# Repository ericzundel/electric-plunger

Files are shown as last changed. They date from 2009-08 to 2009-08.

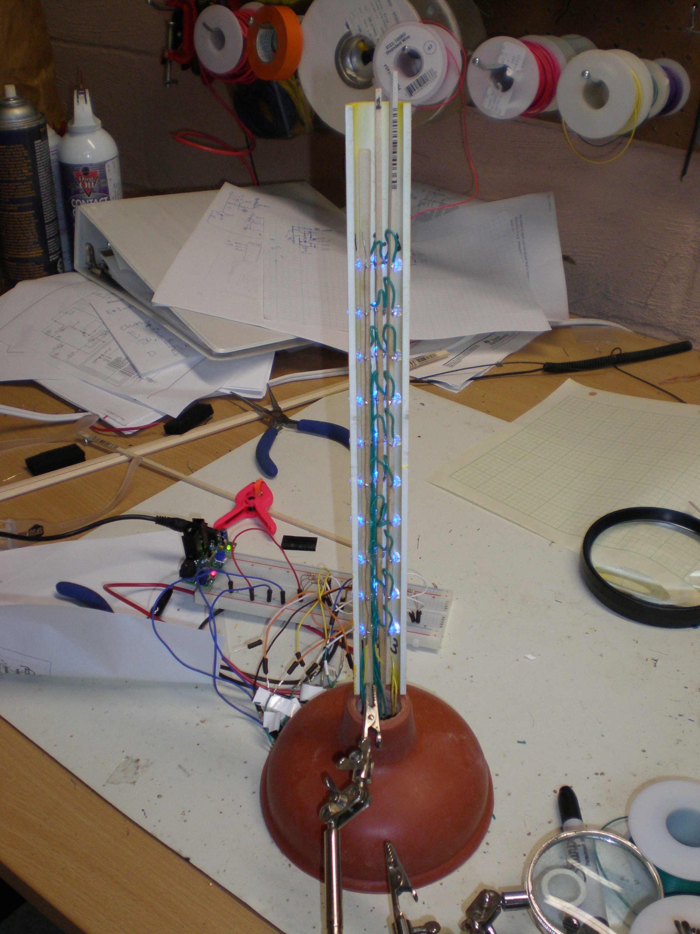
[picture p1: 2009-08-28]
ElectricPlunger/photos/plunger-inside.jpg

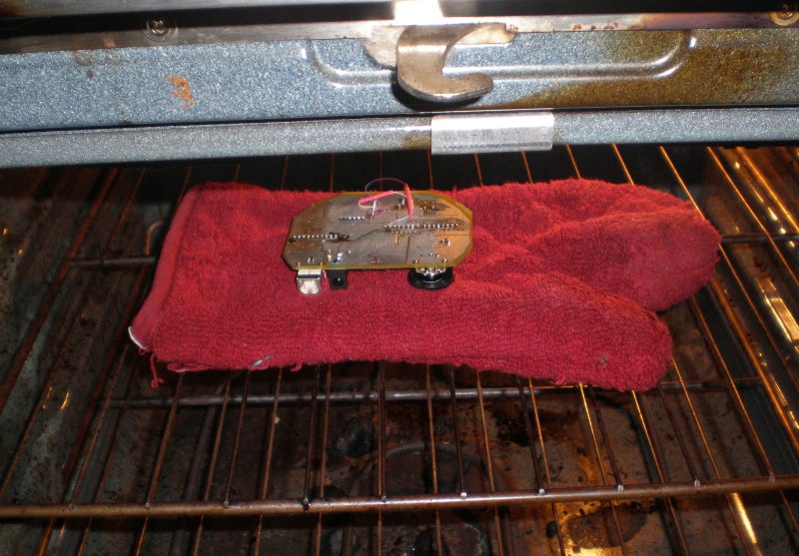
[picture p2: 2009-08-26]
ElectricPlunger/photos/whats-cookin.jpg

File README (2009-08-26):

This is the repo for a project that builds an Electric Plunger.  

ATTRIBUTION:

The plunger circuit and software was written by Eric Z. Ayers.

The plunger circuit is originally based on:

  The Arduino Project: 
    http://arduino.cc
  The Adafruit wave shield by Limor Fried: 
    http://adafruit.com

The software uses:

  The Arduino development environment (version 17) downloadable from:
    http://arduino.cc
  The WaveHC library by Bill Greiman (fat16): 
    http://code.google.com/p/wavehc
  Which in turn was based on Limor Fried's AF_Wave library:
    http;//ladyada.net/

In addition, I used AVRStudio and an AVRISPmkII to flash the bootloader
to the ATMega386P.

LICENSE:

The code, circuits and other materials in this project may be re-used 
or distributed under the terms of the Creative Commons Attribution 3.0 
License.

See LICENSE for more details

SOURCE REPO:

There is a public source code repo that can be accessed with 'git' using the 
remote specification:
  git@github.com:ericzundel/electric-plunger.git

CONTENTS:

ElectricPlunger/  Contains the project files for the ElectricPlunger project
SoundDemo/        Sample code that just plays audio files (no led drivers)
wavelib/          Other goodies from Bill Greimen's WaveHC library
libraries/        Contains the libraries used by the project.

-Eric.
--
Eric Z. Ayers
Aug 26 2009

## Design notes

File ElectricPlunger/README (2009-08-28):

These sketches are a part of the Electric Plunger project.

The plunger has LEDs on its handle that light up and make a show.
There are electronics and a speaker in the base.  The circuit contains
a DAC to play music and a sdcard reader for storing data.

circuit - schematics and board files used to design the electronics.

led_matrix_development - a sketch that drives the LED matrix as a state
    machine.  This was in preparation for writing the LedMatrix library.

led_matrix_demo - a sketch that demonstrates using the LedMatrix library.

led_files - Some sample .led files that are read by the plunger_driver project

photos - Photos of the development of the projecct.

plunger_driver - The code that was actually loaded into the electric plunger
    to read .wav and .led files and display them.

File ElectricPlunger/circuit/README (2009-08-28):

These files pertain the to ElectricPlunger circuit.

plunger-smt.brd - current Eagle 5.6.0 board file (http://cadsoftusa.com)
plunger-smt.sch - current Eagle 5.6.0 schematic file
v0.2/ - a schematic I posted for comments on forums.ladyada.net
v0.2.1/ - the first version of the board I sent off to 4pcb.com for prototyping

The circuit is a mashup of:
  - Arduino Duemilanove board (http://arduino.cc)
  - Adafruit Wave shield  (http://ladyada.net)
  - A custom LED matrix driver

All parts were sourced from Mouser, and the board manufactured by 4pcb.com

DESIGN NOTES:

Power:

- The PTC is a life saver.  Without it I would have burned up the 
  prototypes about a dozen tims.
- The KFBDT regulator data sheets require just 2.2uf caps, but I went 
  conservative and put in bigger 100uf caps.
- Routing a 5V line under the 3.3V output of the 3.3V regulator was a bad 
  idea.  I couldn't see under there and I thoguht I might have shorted the 
  two traces.

Audio:

- Limor Fried suggested that upgrading TL07 opamp to a better audio 
  amp (she suggested an LM386) would be a good idea.
- I fretted over making sure the audio circuit was not noisy.  Getting
  the grounds correct on a mixed analog/digital circuit are norotoriously
  difficult.  I followed the advice I found here:
    http://www.hottconsultants.com/techtips/split-gnd-plane.html
  and here:
    http://www.atmel.com/dyn/resources/prod_documents/doc7633.pdf
  The board turned out well, the audio quality was very good (although 
   not very loud.)
- To eliminate noise, I added decoupling caps around most chips, but not 
  all.  I should make sure each chip has one if I do another board.

USB:
 
- The USB on the v0.2.1 schematic is completely messed up.  
    o TX and RX need to be switched 
    o TEST needs to go to ground
    o DTR needs to be connected to the cap before the RESET
      line (to enable the Arduini auto-reset function)
- When using the USB-TTL cable, the auto-reset doesn't work - you have
  to hit the reset button when the Arduino env. is ready to upload to
  the chip.
- If we intend to have both the on-board USB and the USB-TTL work, there
  has to be some kind of way to isolate so that both TX lines from USB 
  don't interfere with each other (a switch?)

LED Matrix:

- The current limiting resistors mean that each line attached to the 
  ULN2803 should only drive one LED at a time.  I should have put them
  after the PNP transistors because then we could drive 10 LEDs at a time
  instead of only 6, meaning we wouldn't have as much flicker and the 
  matrix might be less timing sensitive.
- After the board was made, someone suggested we add a vibrating motor.  That
  could be driven by one of the spare ULN2803 lines.

MPU:

- I swapped out a 20MHz crystal for the original 16MHz one to try to get rid
  of flicker in the LED matrix (it didn't work.).  This means that I had to
  re-compile a custom bootloader.
- Bringing out all the pins to headers was a good idea. I used this a lot
  for debugging the prototype board.
- I did not wire up the snd enable or brightness controls in the prototype.
  An external button to swich to the next song (or reset the circuit) would
  have been good.
- I considered going to 3.3V on the MPU and then just leaving USB 5V or 
  unregulated power going to the LED matrix.  Then, I could have talked 
  to the SDCard directly with no buffer in between.  However, I would have 
  to add more components for controlling the Led Matrix PNP transistors 
  from 3.3V logic.

Other:

- I didn't really work out how to mount the speaker before assembling 
  everything.   Stuffing it inside the plunger bottom had lots of issues.
   o I tried hot gluing the speaker to the rubber, but it didn't stick.
   o The speaker is heavy and has potential to damage the circuit board
      if it isn't secured
   o the speaker leads are prone to get damaged and will cause crappy sound
   o A speaker mounted inside a rubber plunger bottom is not the ideal
      acoustical environment.

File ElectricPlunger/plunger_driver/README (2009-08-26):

This is the driver shipped with the original Electric plunger on 26 Aug.

It plays .wav files and flashes the LED matrix.
The .wav and .led files must reside in the root directory

The WaveHC file is from http://code.google.com/p/WaveHC
The LedMatrix library is something I wrote.

The WaveHC API accesses the SdReader and FatReader APIs from inside an
interrupt making the LedMatrix flash a lot.  I modified the WaveHC
file to run the LedMatrix state machine more frequently by passing in
a function to run while those libraries are stooging around waiting
for the sdcard to respond.

Notes:

*** Don't leave the plunger turned on with the card un-installed.  The EEPROM 
has a limited number of writes (100,000) over its lifetime.  I fear that 
this would cause the writes to cycle quickly (but this is unconfirmed)

* To further extend the life of the EEPROM, use long LED files and audio clips 
instead of lots of short ones, *or* change th code to write to the EEPROM less 
frequently, if at all.

- The crystal on the original plunger is 20 MHz and the Arduino 
development environment expects 16 MHz board.  I cloned the 16MHz Duemilanove
board description in boards.txt and changed the frequency to 20000000.

-Eric
Wed Aug 26 10:34:33 EDT 2009

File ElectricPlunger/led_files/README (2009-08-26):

These files are the data to drive the LED display.  Format is ASCII.

Each line describes a pattern to display in the LED matrix.  The line length
is 65 characters (including a terminating newline)  The files can be arbitrarily
long.  As a practical matter, the SD cars has a lot of capacity, and since 
there is a stutter in the music when opening a new file, it would be
better to make fewer long files than lots of short files.

The first 4 characters are 4 ascii digits [0-9] that encode the time to display
this sequence in milliseconds.  

The next 60 characters descrive the values for each of the rows.
0 == LED off
1-4 == LED on

(Originally, the matrix could display different intensitites, but when playing 
music and driving the LED, there was unacceptable flickering)

Examples:

Display the first row for 1 second:
1000111111000000000000000000000000000000000000000000000000000000

Display the second row for 1 second:
1000000000111111000000000000000000000000000000000000000000000000

Display the first column for 1 second
1000100000100000100000100000100000100000100000100000100000100000

Display all leds on for a quarter second, then turn them off 
for a quarter second:
0250111111111111111111111111111111111111111111111111111111111111
0250000000000000000000000000000000000000000000000000000000000000

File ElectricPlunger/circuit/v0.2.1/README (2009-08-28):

These are the files that were sent to the PCB fab to make the 
prototype circuit board.

 plunger-smt.brd - EAGLE Circuit board layout (http://cadsoft.de)
 plunger-smt.sch - EAGLE Schematic
 parts.txt - exported parts list from Eagle
 plunger-smt.G?? - gerber files sent to the fab (http://barebonespcb.com)
 plunger-smt.TXT - drill file sent to the fab (http://barebonespcb.com)

Here are the problems I found after v0.2.1:

- The Power adapter had leads that required bigger holes than provided by 
  the part.
- Add a power LED
- Add a power switch
- RS232L and USB-TTL cable: RX and TX need to be swapped.
- RS232RL chip: TEST needs to go to GROUND
- RS232RL chip: needs to have DTR wired to reset, not RTS#
- USB-TTL cable: I added a 1K resistor in series for both RX and TX since 
  it is going between 5V and 3.3V logic
- The USB to TTL cable will not work if the 232RL chip is installed because 
  there will be multiple drivers of the serial line.  Since I couldn't get the 
  on-board USB to work, I cut those traces and used the FTDI USB to TTL cable 
  instead.
- The board would have been better designed with the current limiting resistor
  after the PNP transistors instead of in front of the darlington array.   
  Then the LED matrix could cycle through 6 columns instead of 10 rows 
  (less flicker.)
- Add a connection for an external switch to be mounted on the plunger to 
  advance to the next track.  Could use the reset line on SV8.

Eric Ayers
ericzundel@gmail.com
Wed Aug 26 09:44:39 EDT 2009

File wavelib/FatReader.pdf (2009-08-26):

# Arduino FatReader Library

Copyright (C) 2009 by William Greiman

## Introduction

The Arduino FatReader Library is a minimal implementation of a reader for FAT16 and FAT32 file systems on SD flash memory cards. Standard SD and high capacity SDHC cards are supported.
The FatReader class only supports short 8.3 names.
Short 8.3 names are limited to 8 characters followed by an optional period (.) and extension of up to 3 characters.
The characters may be any combination of uppercase letters and digits. The following special characters are also allowed:
$ % ' - _ @ ~ ` ! ( ) { } ^ # &

## Hardware Configuration

FatReader was developed using an Adafruit Industries Wave Shield. See the Schematic for details.

## Warning

FatReader has been tested with several SD Cards but is bound to contain many bugs. In most companies this would be called pre-alpha software. I hope people will try it and send me comments.

## Bugs and Comments

If you wish to report bugs or have comments, send email to fat16lib@sbcglobal.net.

## References

Adafruit Industries:

http://www.adafruit.com/

http://www.ladyada.net/make/waveshield/

Schematic - http://www.ladyada.net/make/waveshield/download.html The Arduino site:

http://www.arduino.cc/
For more information about FAT file systems see:

http://www.microsoft.com/whdc/system/platform/firmware/fatgen.msp x
For information about using SD cards as SPI devices see:

http://www.sdcard.org/developers/tech/sdcard/pls/Simplified_Physical_Layer_Spec.pdf
The ATmega168 datasheet:

http://www.atmel.com/dyn/resources/prod_documents/doc8025.pdf

# Class Index

## Class List

Here are the classes, structs, unions and interfaces with brief descriptions:

# File Index

## File List

Here is a list of all files with brief descriptions:

Main/WaveHCmainpage.h | Error! Bookmark not defined.

# Class Documentation

## FatReader Class Reference

FatReader implements a minimal FAT16/FAT32 file reader class.

#include <FatReader.h>

Collaboration diagram for FatReader:

### Public Member Functions

- void close (void)
- FatReader (void)
- uint32_t fileSize (void)
- uint32_t firstCluster (void)
- uint8_t isDir (void)
- uint8_t isFile (void)
- uint8_t isOpen (void)

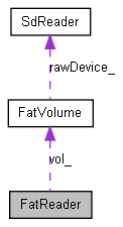
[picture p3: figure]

- uint8_t open (FatReader &dir, char *name)
- uint8_t open (FatVolume &vol, dir_t &dir)
- uint8_t openRoot (FatVolume &vol)
- int16_t read (uint8_t *dst, uint16_t count)
- uint32_t readCluster (void)
- int8_t readDir (dir_t &dir)
- uint32_t readPosition (void)
- void rewind (void)
- uint8_t seekCur (uint32_t pos)
- uint8_t seekSet (uint32_t pos)
- uint8_t type (void)
- FatVolume * volume (void)

### Detailed Description

FatReader implements a minimal FAT16/FAT32 file reader class.

### Constructor & Destructor Documentation

FatReader::FatReader (void) [inline]
Create an instance of FatReader.

### Member Function Documentation

void FatReader::close (void) [inline] Close this instance of FatReader.

uint32_t FatReader::fileSize (void) [inline]

Returns:
The total number of bytes in a file or directory.

uint32_t FatReader::firstCluster (void) [inline]

Returns:
The first cluster number for a file or directory.

uint8_t FatReader::isDir (void) [inline]

Returns:
True if this is a FatReader for a directory else false

uint8_t FatReader::isFile (void) [inline]

Returns:
True if this is a FatReader for a file else false

uint8_t FatReader::isOpen (void) [inline]

Returns:
True if this is a FatReader for an open file/directory else false

uint8_t FatReader::open (FatReader & dir, char * name) Open a file or subdirectory by name.

Note:
The file or subdirectory, name , must be in the specified directory, dir , and must have a DOS 8.3 name.
Parameters:
dir An open FatReader instance for the directory.
name A valid 8.3 DOS name for a file or subdirectory in the directory dir .
Returns:
The value one, true, is returned for success and the value zero, false, is returned for failure. Reasons for failure include the FAT volume has not been initialized, dir is not a directory, name is invalid, the file or subdirectory does not exist, or an I/O error occurred.

uint8_t FatReader::open (FatVolume & vol, dir_t & dir)
Open a file or subdirectory by directory structure.

Parameters:
vol The FAT volume that contains the file or subdirectory.
dir The directory structure describing the file or subdirectory.
Returns:
The value one, true, is returned for success and the value zero, false, is returned for failure. Reasons for failure include the FAT volume, vol , has not been initialized, vol is a FAT12 volume or dir is not a valid directory entry.

uint8_t FatReader::openRoot (FatVolume & vol)
Open a volume's root directory.

Parameters:
vol The FAT volume containing the root directory to be opened.
Returns:
The value one, true, is returned for success and the value zero, false, is returned for failure. Reasons for failure include the FAT volume has not been initialized or it a FAT12 volume.

int16_t FatReader::read (uint8_t * dst, uint16_t count)
Read data from a file at starting at the current read position.

Parameters:
dst Pointer to the location that will receive the data.
count Maximum number of bytes to read.
Returns:
For success read() returns the number of bytes read. A value less than count , including zero, will be returned if end of file is reached. If an error occurs, read() returns -1. Possible errors include read() called before a file has been opened, corrupt file system or an I/O error occurred.

uint32_t FatReader::readCluster (void) [inline]

Returns:
The current cluster number for a file or directory.

int8_t FatReader::readDir (dir_t & dir)
Read the next directory entry from a directory file.

Parameters:
dir The dir_t struct that will receive the data.
Returns:
For success readDir() returns the number of bytes read. A value of zero will be returned if end of file is reached. If an error occurs, readDir() returns -1. Possible errors include readDir() called before a directory has been opened, this is not a directory file or an I/O error occurred.

uint32_t FatReader::readPosition (void) [inline]

Returns:
The read position for a file or directory.

void FatReader::rewind (void)
Set read position to start of file

uint8_t FatReader::seekCur (uint32_t offset)
Set the read position for a file or directory to the current position plus offset .

Parameters:
offset The amount to advance the read position.
Returns:
The value one, true, is returned for success and the value zero, false, is returned for failure.

uint8_t FatReader::seekSet (uint32_t pos) [inline]
Set the read position for a file or directory to pos .

Parameters:
pos The new read position in bytes from the beginning of the file.
Returns:
The value one, true, is returned for success and the value zero, false, is returned for failure.

uint8_t FatReader::type (void) [inline]
Type of this FatReader. You should use isFile() or isDir() instead of type() if possible.

Returns:
The file or directory type.

FatVolume* FatReader::volume (void) [inline] Parent volume

The documentation for this class was generated from the following files:

- C:/Arduino/arduino15/hardware/libraries/WaveHC/FatReader.h
- C:/Arduino/arduino15/hardware/libraries/WaveHC/FatReader.cpp

## FatVolume Class Reference

FatVolume provides access to FAT volumes.

#include <FatReader.h>

Collaboration diagram for FatVolume:

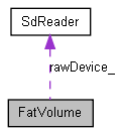
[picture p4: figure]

### Public Member Functions

- uint8_t blocksPerCluster (void)
- uint32_t blocksPerFat (void)
- uint32_t clusterCount (void)
- uint32_t dataStartBlock (void)
- uint8_t fatCount (void)
- uint32_t fatStartBlock (void)
- uint8_t fatType (void)
- FatVolume (void)
- uint8_t init (SdReader &dev, uint8_t part)
- uint8_t init (SdReader &dev)
- SdReader * rawDevice (void)
- uint32_t rootDirEntryCount (void)
- uint32_t rootDirStart (void)
- uint32_t totalBlocks (void)

### Friends

- class FatReader

### Detailed Description

FatVolume provides access to FAT volumes.

### Constructor & Destructor Documentation

FatVolume::FatVolume (void) [inline] Create an instance of FatVolume

### Member Function Documentation

uint8_t FatVolume::blocksPerCluster (void) [inline]

Returns:
The volume's cluster size in blocks.

uint32_t FatVolume::blocksPerFat (void) [inline]

Returns:
The number of blocks in one FAT.

uint32_t FatVolume::clusterCount (void) [inline]

Returns:
The total number of clusters in the volume.

uint32_t FatVolume::dataStartBlock (void) [inline]

Returns:
The logical block number for the start of file data.

uint8_t FatVolume::fatCount (void) [inline]

Returns:
The number of FAT structures on the volume.

uint32_t FatVolume::fatStartBlock (void) [inline]

Returns:
The logical block number for the start of the first FAT.

uint8_t FatVolume::fatType (void) [inline]

Returns:
The FAT type of the volume. Values are 12, 16 or 32.

uint8_t FatVolume::init (SdReader & dev, uint8_t part) Initialize a FAT volume.

Parameters:
dev The SD card where the volume is located.
part The partition to be used. Legal values for part are 1-4 to use the corresponding partition on a device formatted with a MBR, Master Boot Record, or zero if the device is formatted as a super floppy with the FAT boot sector in block zero.
Returns:
The value one, true, is returned for success and the value zero, false, is returned for failure. Reasons for failure include not finding a valid partition, not finding a valid FAT file system in the specified partition or an I/O error.

uint8_t FatVolume::init (SdReader & dev) [inline]
Initialize a FAT volume. Try partition one first then try super floppy format.

Parameters:
dev The SdReader where the volume is located.
Returns:
The value one, true, is returned for success and the value zero, false, is returned for failure. Reasons for failure include not finding a valid partition, not finding a valid FAT file system or an I/O error.

SdReader* FatVolume::rawDevice (void) [inline]
Raw device for this volume uint32_t FatVolume::rootDirEntryCount (void) [inline]

Returns:
The number of entries in the root directory for FAT16 volumes.

uint32_t FatVolume::rootDirStart (void) [inline]

Returns:
The logical block number for the start of the root directory on FAT16 volumes or the first cluster number on FAT32 volumes.

uint32_t FatVolume::totalBlocks (void) [inline]

Returns:
The total number of blocks in the volume.

### Friends And Related Function Documentation

friend class FatReader [friend]
Allow FatReader access to FatVolume private data.

The documentation for this class was generated from the following files:

- C:/Arduino/arduino15/hardware/libraries/WaveHC/FatReader.h
- C:/Arduino/arduino15/hardware/libraries/WaveHC/FatReader.cpp

## SdReader Class Reference

Hardware access class for SD flash cards.

#include <SdReader.h>

### Public Member Functions

- uint32_t cardSize (void)
- uint8_t errorCode (void)
- uint8_t errorData (void)
- uint8_t init (uint8_t slow=0)
- void partialBlockRead (uint8_t value)
- uint8_t readBlock (uint32_t block, uint8_t *dst)
- uint8_t readCID (cid_t &cid)
- uint8_t readCSD (csd_t &csd)
- uint8_t readData (uint32_t block, uint16_t offset, uint8_t *dst, uint16_t count)
- void readEnd (void)

- SdReader (void)
- uint8_t type ()

### Detailed Description

Hardware access class for SD flash cards.
Supports raw access to SD and SDHC flash memory cards.

### Constructor & Destructor Documentation

SdReader::SdReader (void) [inline] Construct an instance of SdReader.

### Member Function Documentation

uint32_t SdReader::cardSize (void)
Determine the size of a SD flash memory card.

Returns:
The number of 512 byte data blocks in the card

uint8_t SdReader::errorCode (void) [inline]

Returns:
error code for last error

uint8_t SdReader::errorData (void) [inline]

Returns:
error data for last error

uint8_t SdReader::init (uint8_t slow = 0) Initialize a SD flash memory card.

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

void SdReader::partialBlockRead (uint8_t value) [inline]
Enable or disable partial block reads.
Enabling partial block reads improves performance by allowing a block to be read over the spi bus as several sub-blocks. Errors will occur if the time between reads is too long since the SD card will timeout.
Use this for applications like the Adafruit Wave Shield.

Parameters:
value The value TRUE (non-zero) or FALSE (zero).)

uint8_t SdReader::readBlock (uint32_t block, uint8_t * dst) [inline] Read a 512 byte block from a SD card device.

Parameters:
block Logical block to be read.
dst Pointer to the location that will receive the data.
Returns:
The value one, true, is returned for success and the value zero, false, is returned for failure.

uint8_t SdReader::readCID (cid_t & cid) [inline]
Read a cards CID register. The CID contains card identification information such as Manufacturer ID, Product name, Product serial number and Manufacturing date.

uint8_t SdReader::readCSD (csd_t & csd) [inline]
Read a cards CSD register. The CSD contains Card-Specific Data that provides information regarding access to the card contents.

uint8_t SdReader::readData (uint32_t block, uint16_t offset, uint8_t * dst, uint16_t count)
Read part of a 512 byte block from a SD card.

Parameters:
block Logical block to be read.
offset Number of bytes to skip at start of block
dst Pointer to the location that will receive the data.
count Number of bytes to read
Returns:
The value one, true, is returned for success and the value zero, false, is returned for failure.

void SdReader::readEnd (void)
Skip remaining data in a block when in partial block read mode.

uint8_t SdReader::type (void) [inline]
Return the card type: SD V1, SD V2 or SDHC

The documentation for this class was generated from the following files:

- C:/Arduino/arduino15/hardware/libraries/WaveHC/SdReader.h
- C:/Arduino/arduino15/hardware/libraries/WaveHC/SdReader.cpp

# File Documentation

## C:/Arduino/arduino15/hardware/libraries/WaveHC/FatReader.cpp File Reference

#include "FatReader.h"

#include <string.h>

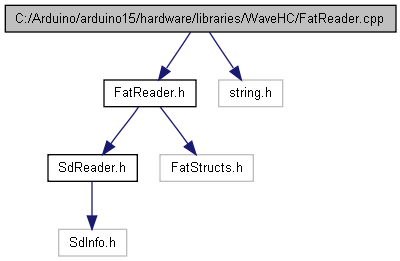
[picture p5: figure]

Include dependency graph for FatReader.cpp:

### Functions

- void dirName (dir_t &dir, char name[])

### Function Documentation

void dirName (dir_t & dir, char name[])
Format the name field of the dir_t struct dir into the 13 byte array name in the standard 8.3 short name format.

## C:/Arduino/arduino15/hardware/libraries/WaveHC/FatReader.h File Reference

#include "SdReader.h"

#include "FatStructs.h"

Include dependency graph for FatReader.h:

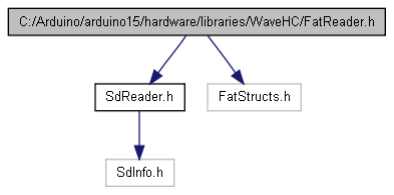
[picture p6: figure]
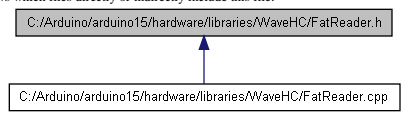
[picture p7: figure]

This graph shows which files directly or indirectly include this file:

### Classes

- class FatReader
FatReader implements a minimal FAT16/FAT32 file reader class.
- class FatVolume
FatVolume provides access to FAT volumes.

### Defines

- #define BPB_COUNT 37
- #define BPB_OFFSET 11
- #define DIR_ATT_FILE_TYPE_MASK (DIR_ATT_VOLUME_ID | DIR_ATT_DIRECTORY)
- #define DIR_IS_FILE(dir) (((dir).attributes & DIR_ATT_FILE_TYPE_MASK) == 0)
- #define DIR_IS_LONG_NAME(dir) (((dir).attributes & DIR_ATT_LONG_NAME_MASK) == DIR_ATT_LONG_NAME)
- #define DIR_IS_SUBDIR(dir) (((dir).attributes & DIR_ATT_FILE_TYPE_MASK) == DIR_ATT_DIRECTORY)
- #define FAT_READER_TYPE_CLOSED 0
- #define FAT_READER_TYPE_MIN_DIR FAT_READER_TYPE_ROOT16
- #define FAT_READER_TYPE_NORMAL 1
- #define FAT_READER_TYPE_ROOT16 2
- #define FAT_READER_TYPE_ROOT32 3
- #define FAT_READER_TYPE_SUBDIR 4
- #define PART_OFFSET (512-64-2)

### Functions

- void dirName (dir_t &dir, char name[])

### Define Documentation

#define BPB_COUNT 37

Byte count for part of BIOS Parameter Block to be read by init()

#define BPB_OFFSET 11

Offset to BIOS Parameter Block in FAT Boot Sector
#define DIR_ATT_FILE_TYPE_MASK (DIR_ATT_VOLUME_ID | DIR_ATT_DIRECTORY)

Mask for file/subdirectory tests

#define DIR_IS_FILE(dir) (((dir).attributes & DIR_ATT_FILE_TYPE_MASK) == 0) Directory entry is for a file

#define DIR_IS_LONG_NAME(dir) (((dir).attributes & DIR_ATT_LONG_NAME_MASK) == DIR_ATT_LONG_NAME)

Directory entry is part of a long name

#define DIR_IS_SUBDIR(dir) (((dir).attributes & DIR_ATT_FILE_TYPE_MASK) == DIR_ATT_DIRECTORY)

Directory entry is for a subdirectory

#define FAT_READER_TYPE_CLOSED 0

This FatReader has not been opened.

#define FAT_READER_TYPE_MIN_DIR FAT_READER_TYPE_ROOT16 Test value for directory type

#define FAT_READER_TYPE_NORMAL 1

FatReader for a file

#define FAT_READER_TYPE_ROOT16 2 FatReader for a FAT16 root directory

#define FAT_READER_TYPE_ROOT32 3 FatReader for a FAT32 root directory

#define FAT_READER_TYPE_SUBDIR 4 FatReader for a subdirectory

#define PART_OFFSET (512-64-2) offset to partition table in mbr

### Function Documentation

void dirName (dir_t & dir, char name[])
Format the name field of the dir_t struct dir into the 13 byte array name in the standard 8.3 short name format.

## C:/Arduino/arduino15/hardware/libraries/WaveHC/SdReader.cpp File Reference

#include "wiring.h"

#include "SdReader.h"

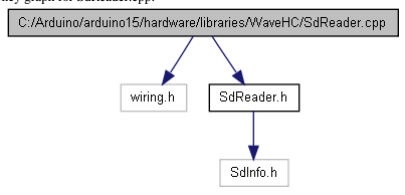
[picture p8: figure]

Include dependency graph for SdReader.cpp:

### Defines

- #define DATA_RES_ACCEPTED 0X05
- #define DATA_RES_CRC_ERROR 0X0B
- #define DATA_RES_MASK 0X1F
- #define DATA_RES_WRITE_ERROR 0X0D
- #define DATA_START_BLOCK 0XFE
- #define MISO 12
- #define MOSI 11
- #define R1_IDLE_STATE 1
- #define R1_READY_STATE 0
- #define SCK 13
- #define SS 10

### Functions

- uint8_t spiRec (void)
- void spiSend (uint8_t b)
- void spiSSHigh (void)
- void spiSSLow (void)

### Define Documentation

#define DATA_RES_ACCEPTED 0X05 write data accepted token

#define DATA_RES_CRC_ERROR 0X0B write data crc error token

#define DATA_RES_MASK 0X1F

mask for data response tokens after a write block operation

#define DATA_RES_WRITE_ERROR 0X0D

write data programming error token

#define DATA_START_BLOCK 0XFE start data token for read or write

#define MISO 12

spi master input, slave output pin

#define MOSI 11

spi master output, slave input pin

#define R1_IDLE_STATE 1

status for card in the idle state

#define R1_READY_STATE 0

status for card in the ready state

#define SCK 13

spi serial clock pin

#define SS 10

Slave Select pin for card

### Function Documentation

uint8_t spiRec (void) [inline] Receive a byte from the card

void spiSend (uint8_t b) [inline] Send a byte to the card void spiSSHigh (void) [inline] Set Slave Select high

void spiSSLow (void) [inline] Set Slave Select low

## C:/Arduino/arduino15/hardware/libraries/WaveHC/SdReader.h File Reference

#include "SdInfo.h"

Include dependency graph for SdReader.h:

This graph shows which files directly or indirectly include this file:

### Classes

- class SdReader
Hardware access class for SD flash cards.

### Defines

- #define ACMD41 0X29
- #define CMD0 0X00
- #define CMD10 0X0A
- #define CMD17 0X11
- #define CMD55 0X37
- #define CMD58 0X3A
- #define CMD8 0X08

- #define CMD9 0X09
- #define SD_CARD_ERROR_ACMD41 0X6
- #define SD_CARD_ERROR_BAD_CSD 0X7
- #define SD_CARD_ERROR_CMD0 0X1
- #define SD_CARD_ERROR_CMD17 0X3
- #define SD_CARD_ERROR_CMD24 0X4
- #define SD_CARD_ERROR_CMD58 0X5
- #define SD_CARD_ERROR_CMD8 0X2
- #define SD_CARD_ERROR_READ 0X10
- #define SD_CARD_ERROR_READ_REG 0X8
- #define SD_CARD_ERROR_WRITE 0X20
- #define SD_CARD_ERROR_WRITE_BLOCK_ZERO 0XA
- #define SD_CARD_ERROR_WRITE_TIMEOUT 0X9
- #define SD_CARD_INFO_SUPPORT 1
- #define SD_CARD_TYPE_SD1 1
- #define SD_CARD_TYPE_SD2 2
- #define SD_CARD_TYPE_SDHC 3

### Define Documentation

#define ACMD41 0X29

SD_SEND_OP_COMD - Sends host capacity support information and activates the card's initialization process

#define CMD0 0X00

GO_IDLE_STATE - init card in spi mode if CS low

#define CMD10 0X0A

SEND_CID - read the card identification information (CID register)

#define CMD17 0X11

READ_BLOCK - read a single data block from the card

#define CMD55 0X37

APP_CMD - escape for application specific command

#define CMD58 0X3A

READ_OCR - read the OCR register of a card

#define CMD8 0X08

SEND_IF_COND - verify SD Memory Card interface operating condition.

#define CMD9 0X09

SEND_CSD - read the Card Specific Data (CSD register)

#define SD_CARD_ERROR_ACMD41 0X6 card's ACMD41 initialization process timeout

#define SD_CARD_ERROR_BAD_CSD 0X7 card returned a bad CSR version field

#define SD_CARD_ERROR_CMD0 0X1 timeout error for command CMD0

#define SD_CARD_ERROR_CMD17 0X3

card returned an error response for CMD17 (read block)

#define SD_CARD_ERROR_CMD24 0X4

card returned an error response for CMD24 (write block)

#define SD_CARD_ERROR_CMD58 0X5

card returned an error response for CMD58 (read OCR)

#define SD_CARD_ERROR_CMD8 0X2

CMD8 was not accepted - not a valid SD card

#define SD_CARD_ERROR_READ 0X10

card returned an error token instead of read data

#define SD_CARD_ERROR_READ_REG 0X8 read CID or CSD failed

#define SD_CARD_ERROR_WRITE 0X20

card returned an error token as a response to a write operation

#define SD_CARD_ERROR_WRITE_BLOCK_ZERO 0XA attempt to write protected block zero

#define SD_CARD_ERROR_WRITE_TIMEOUT 0X9 timeout occurred during write programming

#define SD_CARD_INFO_SUPPORT 1

Optional readCID(), readCSD() and cardSize() if nonzero

#define SD_CARD_TYPE_SD1 1

Standard capacity V1 SD card

#define SD_CARD_TYPE_SD2 2 Standard capacity V2 SD card

#define SD_CARD_TYPE_SDHC 3 High Capacity SD card

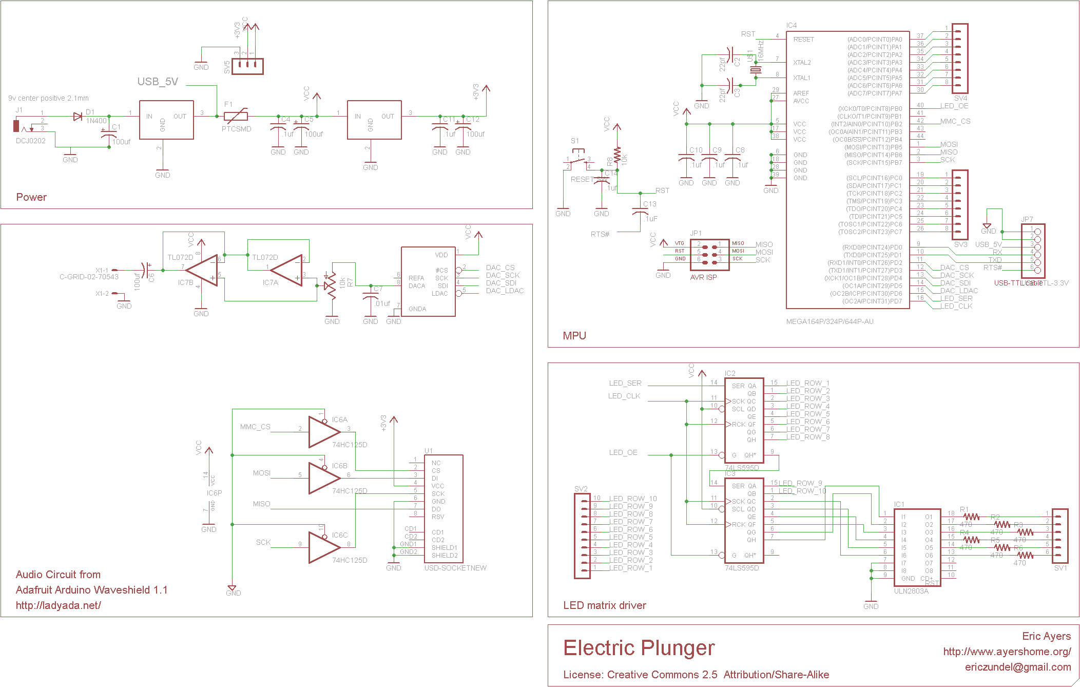
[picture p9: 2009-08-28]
ElectricPlunger/circuit/plunger_schematic_2009-08-09.png

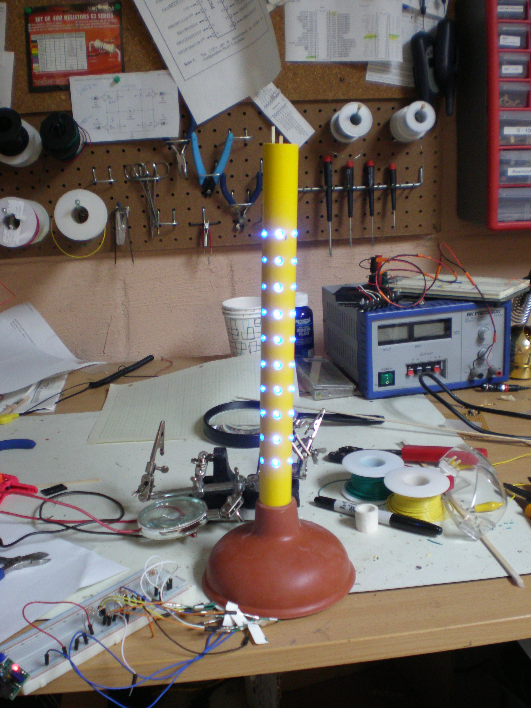
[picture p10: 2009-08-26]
ElectricPlunger/photos/plunger-inprogress.jpg

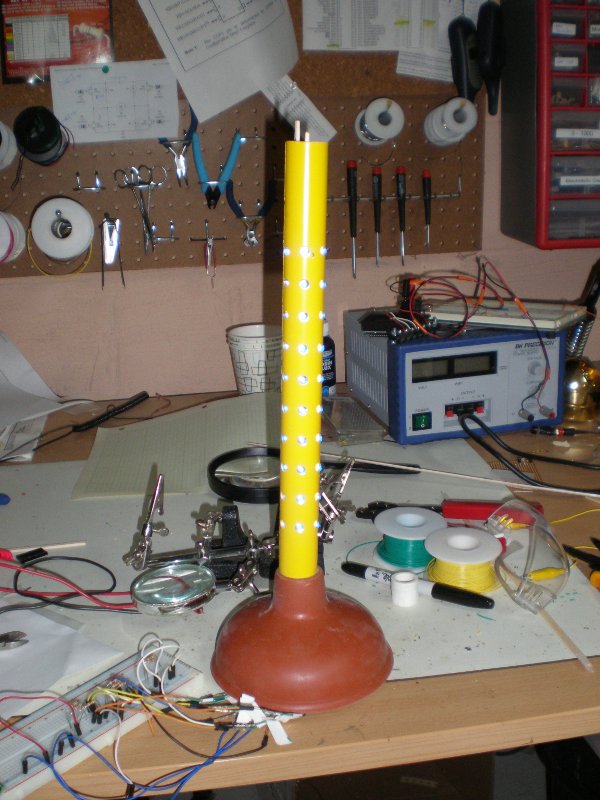
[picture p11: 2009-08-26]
ElectricPlunger/photos/mock-up.jpg

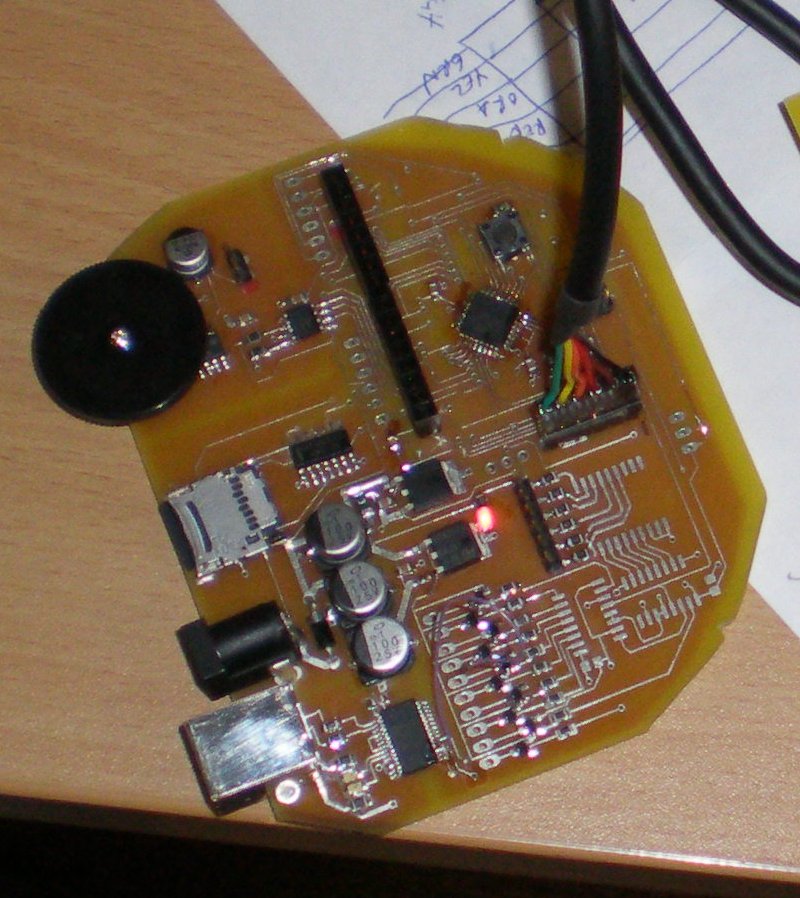
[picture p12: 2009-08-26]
ElectricPlunger/photos/board-with-ttl-cable.jpg

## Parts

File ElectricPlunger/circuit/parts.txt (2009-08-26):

Partlist

Exported from plunger-smt.sch at 8/15/2009 11:53:23 AM

EAGLE Version 5.6.0 Copyright (c) 1988-2009 CadSoft

Part     Value                   Device                  Package         Library     Sheet

C1       100uf                   CPOL-USE                PANASONIC_E     resistor    1
C2       22pf                    C-USC0805               C0805           rcl         1
C3       22pf                    C-USC0805               C0805           rcl         1
C4       .1uf                    C-USC0805               C0805           resistor    1
C5       100uf                   CPOL-USE                PANASONIC_E     resistor    1
C6       100uf                   CPOL-USD                PANASONIC_D     resistor    1
C7       .01uf                   C-USC0805               C0805           rcl         1
C8       .1uf                    C-USC0805               C0805           rcl         1
C10      .1uf                    C-USC0805               C0805           rcl         1
C11      .1uf                    C-USC0805               C0805           resistor    1
C12      100uf                   CPOL-USE                PANASONIC_E     resistor    1
C13      .1uf                    C-USC0805               C0805           rcl         1
C14      .1uf                    C-USC0805               C0805           rcl         1
C15      .1uf                    C-USC0805               C0805           rcl         1
C17      .1uf                    C-USC0805               C0805           rcl         1
C18      .1uf                    C-USC0805               C0805           rcl         1
D1       1N4001                  DIODEPTH                DIODE-1N4001    SparkFun    1
F1       PTCSMD                  PTCSMD                  PTC-1206        SparkFun    1
IC1      ULN2803A                ULN2803AULN2803ADW      SO18W           uln-udn     1
IC2      74LS595D                74LS595D                SO16            74xx-us     1
IC3      74LS595D                74LS595D                SO16            74xx-us     1
IC4      ATMEGA168-AU            ATMEGA168-AU            TQFP32-08       Arduino-AVR 1
IC5      FT232RL                 FT232RL                 SSOP28          ftdichip    1
IC6      74HC125D                74HC125D                SO14            74xx-eu     1
IC7      TL072D                  TL072D                  SO08            linear      1
J1       DCJ0202                 DCJ0202                 DCJ0202         con-jack    1
JP1      AVR-ISP-6               AVR-ISP-6               AVR-ISP-6       avr-5-4.16  1
JP7      USB-TTL-3.3V            PINHD-1X6CLEAN          1X06-CLEAN      carduino    1
LED1                             LEDCHIPLED_0805         CHIPLED_0805    led         1
LED2                             LEDCHIPLED_0805         CHIPLED_0805    led         1
R1       470                     R-US_R0805              R0805           resistor    1
R2       470                     R-US_R0805              R0805           resistor    1
R3       470                     R-US_R0805              R0805           resistor    1
R4       470                     R-US_R0805              R0805           resistor    1
R5       470                     R-US_R0805              R0805           resistor    1
R6       470                     R-US_R0805              R0805           resistor    1
R7       4.7k                    R-US_R0805              R0805           resistor    1
R8       10k                     R-US_R0805              R0805           rcl         1
R9       1.5k                    R-US_R0805              R0805           rcl         1
R10      100k                    R-US_R0805              R0805           rcl         1
R11      470                     R-US_R0805              R0805           resistor    1
R12      470                     R-US_R0805              R0805           resistor    1
R13      100                     R-US_R0805              R0805           rcl         1
R14      68                      R-US_R0805              R0805           resistor    1
R15      10k                     TRIM_US-S63S            S63S            pot         1
R16      68                      R-US_R0805              R0805           resistor    1
R17      4.7k                    R-US_R0805              R0805           resistor    1
R18      4.7k                    R-US_R0805              R0805           resistor    1
R19      4.7k                    R-US_R0805              R0805           resistor    1
R20      4.7k                    R-US_R0805              R0805           resistor    1
R21      4.7k                    R-US_R0805              R0805           resistor    1
R22      4.7k                    R-US_R0805              R0805           resistor    1
R23      4.7k                    R-US_R0805              R0805           resistor    1
R24      4.7k                    R-US_R0805              R0805           resistor    1
R25      4.7k                    R-US_R0805              R0805           resistor    1
REG3.3   KFBDT                   KFBDT                   DPACK           eza-custom  1
REG5.5   KFBDT                   KFBDT                   DPACK           eza-custom  1
S1       RESET SW                TAC_SWITCHPTH           TACTILE-PTH     SparkFun    1
S2                               SWITCH-SPSTPTH          SWITCH-SPDT     SparkFun    1
SV1                              MA06-1                  MA06-1          con-lstb    1
SV2                              MA10-1                  MA10-1          con-lstb    1
SV3                              MA08-1                  MA08-1          con-lstb    1
SV4                              FE06-1                  FE06            con-lsta    1
SV7                              MA08-1                  MA08-1          con-lstb    1
SV8                              FE06-1                  FE06            con-lsta    1
T1                               BC807-16-PNP-SOT23-BEC  SOT23-BEC       transistor  1
T2                               BC807-16-PNP-SOT23-BEC  SOT23-BEC       transistor  1
T3                               BC807-16-PNP-SOT23-BEC  SOT23-BEC       transistor  1
T4                               BC807-16-PNP-SOT23-BEC  SOT23-BEC       transistor  1
T5                               BC807-16-PNP-SOT23-BEC  SOT23-BEC       transistor  1
T6                               BC807-16-PNP-SOT23-BEC  SOT23-BEC       transistor  1
T7                               BC807-16-PNP-SOT23-BEC  SOT23-BEC       transistor  1
T8                               BC807-16-PNP-SOT23-BEC  SOT23-BEC       transistor  1
T9                               BC807-16-PNP-SOT23-BEC  SOT23-BEC       transistor  1
T10                              BC807-16-PNP-SOT23-BEC  SOT23-BEC       transistor  1
TM1                              THUMBPOT                THUMBWHEEL      ashield     1
U$1      16MHz                   CRYTALTC26H             TC26H           crystal     1
U$2      MCP4921                 MCP4921                 SO8             eza-custom  1
U$3      HIROSE-MICRO-SD-DM3C-SF HIROSE-MICRO-SD-DM3C-SF HIROSE-SD-MICRO eza-custom  1
X1       C-GRID-02-70543         C-GRID-02-70543         70543-02        con-molex   1
X2       USBPTH                  USBPTH                  USB-B-PTH       SparkFun    1

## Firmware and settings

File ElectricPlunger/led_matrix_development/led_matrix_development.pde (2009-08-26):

/* 
 * LED Matrix Driver for Electric Plunger
 *
 * The 'top' part of the circuit is 10 PNP transistor. The 'bottom' 
 * part of the circuit uses 6 pins of a ULN2803A Darlington array.
 *
 * Between these transistors are are wired to a 10x6 LED array.
 *
 * The matrix is controlled by a pair of 74HC595 serial to parallel 
 * 8 bit shift registers hooked up together to make a single logical 
 * 16 bit shift register.  This register requires only 3 pins from the mpu.
 *
 * The controls:
 *
 * bits 10-15 are to the Darlington array.  Raise high to switch on.
 * bits 0-9 are to the PNP transistors. Pull low to switch on.
 * b0000000000111111 turns all leds on
 * b0111111111000001 turns on the upper left led
 * 
 * Each column is wired with a single current limiting resistor.  Therefore, 
 * only one row should be displayed at a time.  The logic below cycles
 * through each of the 10 rows, turning on the single row PNP transisitor
 * and then enabling each column that should be displayed for that row.
 */

#define DEBUG 1

static int led_data_pin = 8;
static int led_clock_pin = 7;
static int led_output_enable_pin = 6;


#define ROW_1 (1)    // Bottom row
#define ROW_2 (1<<2)
#define ROW_3 (1<<3)
#define ROW_4 (1<<4)
#define ROW_5 (1<<5)
#define ROW_6 (1<<6)
#define ROW_7 (1<<7)
#define ROW_8 (1<<8)
#define ROW_9 (1<<9)
#define ROW_10 (1<<10)
#define NUM_ROWS 10

#define COLUMN_START_BIT 10
#define COLUMN_1 (1)
#define COLUMN_2 (1<<2)
#define COLUMN_3 (1<<3)
#define COLUMN_4 (1<<4)
#define COLUMN_5 (1<<5)
#define COLUMN_6 (1<<6)
#define NUM_COLS 6

void setup() {
  // Communicate to the 74HC595 over 3 pins
  pinMode(led_data_pin, OUTPUT);
  pinMode(led_clock_pin, OUTPUT);
  pinMode(led_output_enable_pin, OUTPUT);

#if DEBUG
  // Serial console for debugging
  Serial.begin(9600);
  Serial.println("Starting");
#endif

}

/*
 * Used by the LED driver
 */
#define LED_COLUMN_DISPLAY_CYCLE 50000


#define LED_STATE_IDLE             0
#define LED_STATE_NEW_DATA         1
#define LED_STATE_COMPUTE_NEXT_ROW 2
#define LED_STATE_DISPLAY_ROW      3

typedef struct led_driver {
  int state;
  unsigned long last_action_time;
  // each LED can have intensity 0-9, sorted as ascii chars
  char led_values[NUM_ROWS][NUM_COLS]; 
  int current_row;
};
struct led_driver led_driver_data;

int led_idle() {
  return LED_STATE_IDLE;
}

int led_new_data() {
  led_driver_data.current_row = 0;
  led_driver_data.last_action_time = micros();
  return LED_STATE_COMPUTE_NEXT_ROW;
}

int led_compute_next_row() {
  unsigned long columns = 0;
  for (int i = 0; i < NUM_COLS; i++) {
    columns = columns << 1;
    int led_value = 
        led_driver_data.led_values[led_driver_data.current_row][i];
    if (led_value > '0') {
      columns++;
    }
  }

  // Send the column to the shift register
  unsigned long int to_shift_register =
        (~(1L << led_driver_data.current_row) & 0x03FF)
        | (columns << COLUMN_START_BIT);

#if DEBUG
  // Serial.print(" Calculated data: ");
  // Serial.println(to_shift_register, BIN);
  // delay(100);
#endif

  // turn off all outputs
  digitalWrite(led_output_enable_pin, HIGH);

#if DEBUG
  /* Serial.print("    Writing data: ");*/
#endif

  // shift the data out msbit first
  for (long index = 15; index >= 0; --index) {
    digitalWrite(led_clock_pin, LOW);
    char bit = ((to_shift_register & (1 << index)) > 0) ? HIGH : LOW;
    // Serial.print(bit, DEC);
    digitalWrite(led_data_pin, bit);
    digitalWrite(led_clock_pin, HIGH);
  }

#if DEBUG  
  /* Serial.println(" ");*/
#endif

  // Toggle the clock low & high once more to push the last bit to 
  // the register.
  digitalWrite(led_clock_pin, LOW);
  digitalWrite(led_clock_pin, HIGH);

  digitalWrite(led_output_enable_pin, LOW);

  // Remember the time this executed so we can compute elapsed time
  led_driver_data.last_action_time = micros();

  return LED_STATE_DISPLAY_ROW;
}

int led_displaying_row() {
  // Just wait around displaying the led
  if ((micros() - led_driver_data.last_action_time) 
          > LED_COLUMN_DISPLAY_CYCLE) {
    if (++led_driver_data.current_row >= NUM_ROWS) {
      led_driver_data.current_row = 0;
      return LED_STATE_IDLE;
    }
    return LED_STATE_COMPUTE_NEXT_ROW;
  }
  return LED_STATE_DISPLAY_ROW;
}

void led_state_machine() {
  int next_state;

#if DEBUG  
  // Serial.print("In state: ");
  // Serial.println(led_driver_data.state);
  // delay(500);
#endif

  switch(led_driver_data.state) {
  case LED_STATE_IDLE:
    next_state = led_idle();
    break;
  case LED_STATE_NEW_DATA:
    next_state = led_new_data();
    break;
  case LED_STATE_COMPUTE_NEXT_ROW:
    next_state = led_compute_next_row();
    break;
  case LED_STATE_DISPLAY_ROW:
    next_state = led_displaying_row();
    break;
  default:
    Serial.print("Unknown state: ");
    Serial.println(led_driver_data.state);
    next_state = LED_STATE_IDLE;
  }

  if (next_state != led_driver_data.state) {
#if DEBUG  
    // for debugging
    // Serial.print("In state: ");
    // Serial.print(led_driver_data.state);
    // Serial.print(" To state: ");
    // Serial.println(next_state);
#endif
    led_driver_data.state = next_state;
  }

}

char led_is_ready() {
  return (led_driver_data.state == LED_STATE_IDLE ? 1 : 0);
}

void display_leds(char* values) {
  for (int i = 0; i < NUM_ROWS; ++i) {
    for (int j = 0; j < NUM_COLS; ++j) {
      led_driver_data.led_values[i][j] = *values;
      values++;
    }
  }

#if DEBUG
/*
  for (int i = 0; i < NUM_COLS; ++i) {
    Serial.print("column: ");
    Serial.print(i);
    Serial.print(": ");
    for (int j = 0; j < NUM_ROWS; ++j) {
      Serial.print(led_driver_data.led_values[i][j], BYTE);
    }
    Serial.println("");
  }
*/
#endif
  
  led_driver_data.state = LED_STATE_NEW_DATA;
}

static int state = 0;
static unsigned long last_change = 0;
void loop() {
  led_state_machine();

  if (led_is_ready()) {
     switch(state) {
    case 0:
      display_leds("111111" 
                   "000000" 
                   "000000" 
                   "000000" 
                   "000000"
                   "000000" 
                   "000000" 
                   "000000" 
                   "000000" 
                   "000000");
      break;
    case 1:
      display_leds("100000" 
		   "100000" 
		   "010000" 
		   "010000" 
 		   "001000"
                   "001000" 
                   "000100" 
		   "000100" 
		   "000010" 
                   "000010");
      break;
    case 2:
      display_leds("001000" 
                   "000100" 
                   "000100" 
                   "000010" 
                   "000010"
                   "100000" 
                   "100000" 
                   "010000" 
                   "010000" 
                   "001000");
      break;
    case 3:
      display_leds("111111" 
                   "111111" 
                   "111111" 
                   "111111" 
                   "111111" 
                   "111111" 
                   "111111" 
                   "111111" 
                   "111111" 
                   "111111");
      break;
    default:
      state = 0;
      break;
    }
    if ((millis() - last_change) > 5000) {
      state++;
      last_change = millis();    
    }
  }

}

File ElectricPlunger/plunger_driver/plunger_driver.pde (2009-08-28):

/*
 * Electric plunger driver
 * 
 * Copyright 2009 Eric Z Ayers
 *
 * License: Creative Commons Attribution 3.0 
 * See LICENSE file for more details
 *
 */

#include <LedMatrix.h>
#include <FatReader.h>
#include <SdReader.h>
#include <avr/pgmspace.h>
#include "WaveUtil.h"
#include "WaveHC.h"

#define DEBUG 0

SdReader card;
FatVolume vol;
uint8_t dirLevel; // indent level for file/dir names
dir_t dirBuf;     // buffer for directory reads

int next_wav_index;
int next_led_index;

/* Returns the number of bytes currently free in RAM */
int freeRam(void)
{
  extern int  __bss_end; 
  extern int  *__brkval; 
  int free_memory; 
  if((int)__brkval == 0) {
    free_memory = ((int)&free_memory) - ((int)&__bss_end); 
  }
  else {
    free_memory = ((int)&free_memory) - ((int)__brkval); 
  }
  return free_memory; 
} 

/* Print error message and halt if SD I/O error */
static void sdErrorCheck(void)
{
  if (!card.errorCode()) return;
  putstring("\n\rSD I/O error: ");
  Serial.print(card.errorCode(), HEX);
  putstring(", ");
  Serial.println(card.errorData(), HEX);
  while(1);
}

static bool isWavFile(dir_t&); // decl
static bool isLedFile(dir_t&); // decl

static bool FindNextWavFile(FatReader& dir, int* last_index) {
  int index = 0;
  dir.rewind();
  while (dir.readDir(dirBuf) > 0) {
    if (dirBuf.name[0] == '.' || !isWavFile(dirBuf))
      continue;
    index++;
    if (index > *last_index) {
      *last_index = index;
      return true;
    }
  }
  *last_index = 0;
  return false;
}

static bool FindNextLedFile(FatReader& dir, int* last_index) {
  int index = 0;
  dir.rewind();
  while (dir.readDir(dirBuf) > 0) {
    if (dirBuf.name[0] == '.' || !isLedFile(dirBuf))
      continue;
    index++;
    if (index > *last_index) {
      *last_index = index;
      return true;
    }
  }
  *last_index = 0;
  return false;
}

/* Pretty prints a FAT 8.3 filename */
static void printName(dir_t &dir)
{
  for (uint8_t i = 0; i < 11; i++) {
    if (dir.name[i] == ' ')continue;
    if (i == 8) Serial.print('.');
    Serial.print(dir.name[i]);
  }
  if (DIR_IS_SUBDIR(dir)) Serial.print('/');
}

/***********************************************************
 *  Wave file control logic
 ***********************************************************/

/* Stores the state of playing the .wav file between loops() */
struct wave_state {
  FatReader wave_file;
  FatReader root;
};
static struct wave_state wstate;

/* Wave playing library object */
WaveHC wave;      // only one allowed!

static bool isWavFile(dir_t &dir)
{
  if (DIR_IS_SUBDIR(dir)) {
    return false;
  }
  if (dir.name[8] == 'W' && dir.name[9] == 'A' && dir.name[10] == 'V') {
    return true;
  }
  return false;
}

/* Starts up each new .wav file as they complete. */
static void wave_play_loop() {
  if (wave.isplaying) {
    return;
  }
  // sdErrorCheck();
  if (FindNextWavFile(wstate.root, &next_wav_index)) {
    if (!wstate.wave_file.open(vol, dirBuf)) {
      // Serial.print("Failed to open WAV file: ");
      // printName(dirBuf);
    } else if (!wave.create(wstate.wave_file)) {
      // Serial.print(" Not a valid WAV: ");
      // printName(dirBuf);
    } else {
#if DEBUG
      Serial.print("Playing WAV file: ");
      printName(dirBuf);
#endif
      wave.play();
    }
  }
}

/***********************************************************
 *  LED Matrix control logic
 ***********************************************************/

struct led_state {
  FatReader led_file;
  unsigned long last_action_time;
  int time_to_next_read;

  // Each line is 4 chars of millisecond duration + 60 chars of LED data + n/l
#define LINE_BUF_SIZE 65
  char line_buf[LINE_BUF_SIZE];
  FatReader root;
};

struct led_state lstate;
// ApuPlunger pin outs

// LED Matrix
// data pin = 7
// clock pin = 8
// output enable pin = 6
LedMatrix matrix(7,8,6);

static bool isLedFile(dir_t &dir)
{
  if (DIR_IS_SUBDIR(dir)) {
    return false;
  }
  if (dir.name[8] == 'L' && dir.name[9] == 'E' && dir.name[10] == 'D') {
    return true;
  }
  return false;
}

// Read the next line of data from the file.
static void read_next_line() {
  noInterrupts();
  int result = lstate.led_file.read((uint8_t*)lstate.line_buf, 
                                      LINE_BUF_SIZE);
  interrupts();

  if (result != LINE_BUF_SIZE) {
    // EOF or error
#if DEBUG
    Serial.print("Got result: ");
    Serial.print(result, DEC);
    Serial.println(".  Going to next file");
#endif
    lstate.led_file.close();
  }

  lstate.time_to_next_read = 
      (lstate.line_buf[0] - '0') * 1000 +
      (lstate.line_buf[1] - '0') * 100 +
      (lstate.line_buf[2] - '0') * 10 +
      (lstate.line_buf[3] - '0');
}

static void led_loop() {
  matrix.RunStateMachine();

  if (!matrix.IsReady()) {
    return;
  }

  long unsigned int elapsed = millis() - lstate.last_action_time;
  if (elapsed < lstate.time_to_next_read) {
    // Display the current LED data

    // The first 4 chars are the time in milliseconds to display this data
    // The next 60 chars are the led values [0-9]
    matrix.DisplayLeds(&lstate.line_buf[4]);
    return;
  }

  // The time to expire the current set of data has expired.
  lstate.last_action_time = millis();
  if (lstate.led_file.isOpen()) {
    read_next_line();    
    return;
  }

  // No more data in this file.  Open the next file 
  noInterrupts();
  while (1) {
    // Will return false when we reach the end.
    if (!FindNextLedFile(lstate.root, &next_led_index))
      continue;

    // Not expected.      
    if (!lstate.led_file.open(vol, dirBuf)) {
      Serial.println("led_file.open failed");
      continue;
    }
    // We have a new file open now.
    break;
  }
  interrupts();
}

static void busy_func() {
  matrix.RunStateMachineFromInterrupt();
}

static void GetFileCounts(FatReader& dir, int* wav_count, int* led_count) {
  dir.rewind();
  while (dir.readDir(dirBuf) > 0) {
    if (dirBuf.name[0] == '.')
      continue;
     else if (isLedFile(dirBuf))
      (*led_count)++;
     else if (isWavFile(dirBuf))
      (*wav_count)++;
  }
}

/******************************************************************************
 *  Main Entry Points
 *****************************************************************************/
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

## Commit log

2009-08-26 Updates in the project file.
    [plunger-smt.brd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]
2009-08-26 LED patterns added
2009-08-26 Added docs to LedMatrix library.
2009-08-26 Added some notes to the schematic and some photos.
    [plunger-smt.brd, plunger-smt.sch]
2009-08-27 Updated some comments in the LED Matrix that were borken
    [plunger-smt.sch]
2009-08-28 Moved the circuit files around into a subdirectory.
    [plunger-smt.brd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]
